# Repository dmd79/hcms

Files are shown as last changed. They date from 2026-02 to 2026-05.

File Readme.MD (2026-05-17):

# HCMS Scientific Calculator

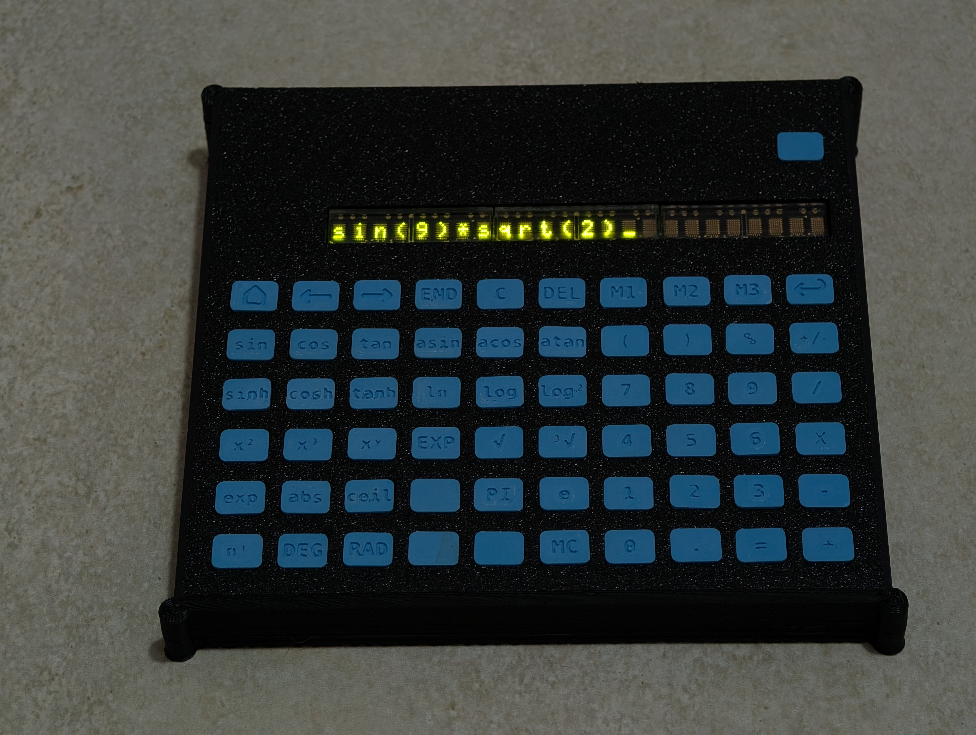
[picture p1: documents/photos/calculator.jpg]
HCMS Scientific Calculator


A handmade scientific calculator built with an ESP32-S3 microcontroller, Broadcom HCMS-2913 LED dot-matrix displays, and a custom 6×10 matrix keypad — all running on [ESPHome](https://esphome.io/).

---

## Features

- 24-character scrolling LED display (3× HCMS-2913 chained)
- 60-key matrix keypad (6 rows × 10 columns)
- Full scientific calculator: arithmetic, trigonometry, logarithms, powers, factorials, constants
- Degree / Radian toggle
- 3-slot memory system (MEM1, MEM2, MEM3 + MCLR)
- UNDO function
- Cursor navigation (HOME, END, `<`, `>`, DEL)
- Settings menu: brightness, display timeout, auto power-off, firmware version
- Auto power-off with configurable timeout
- Autorepeat on `<`, `>`, DEL
- LiPo battery powered with USB-C charging

---

## Supported Operations

| Category | Keys |
|---|---|
| Arithmetic | `+` `-` `×` `/` `%` `=` `+/-` |
| Powers | `x²` `x³` `xʸ` `√x` |
| Trigonometry | `sin` `cos` `tan` `asin` `acos` `atan` `sinh` `cosh` `tanh` |
| Logarithms | `log` `ln` `log2` `exp` `eˣ` |
| Rounding | `floor` `ceil` `round` `abs` |
| Constants | `e` `π` |
| Angle mode | `deg` `rad` |
| Memory | `MEM1` `MEM2` `MEM3` `MCLR` |
| Editing | `DEL` `UNDO` `HOME` `END` `<` `>` `CANC` |

---

## Hardware

### Main Components

| Component | Description |
|---|---|
| ESP32-S3-WROOM-1-N16R8 | Main microcontroller (16MB flash, 8MB PSRAM) |
| HCMS-2913 × 3 | 5×7 dot-matrix LED display modules, chained |
| KH-6×6×6H tactile switches × 60 | Matrix keypad switches |

### Power Supply

The calculator is powered by a single-cell LiPo battery. Two additional modules are required:

**LiPo Charger (USB-C)** — charges the battery via USB-C connector.  
[Buy on Amazon (R3028, 18×14mm)](https://www.amazon.it/dp/B0F59VQ8JC)

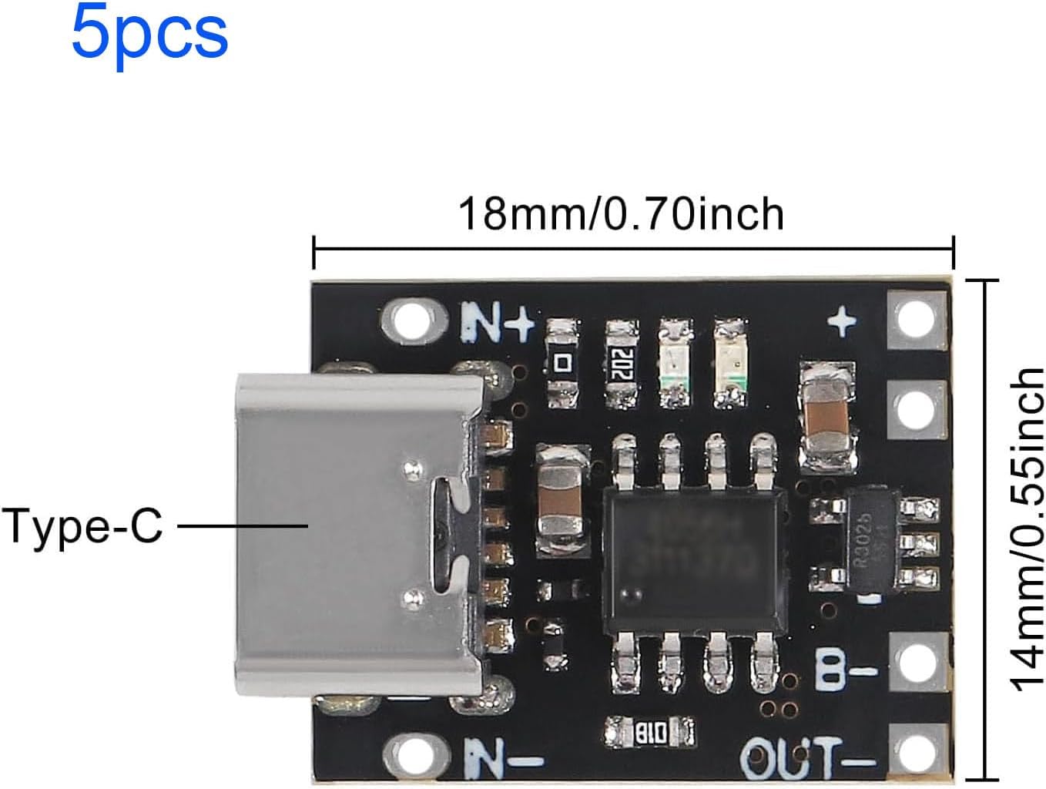
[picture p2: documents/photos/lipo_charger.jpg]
LiPo Charger


**DC-DC Step-Down Converter** — converts battery voltage to a stable 3.3V for the ESP32 and display logic.  
[Buy on Amazon (Mini DC-DC, adjustable)](https://www.amazon.it/Converter-LAOMAO-convertitore-regolabile-alimentatore/dp/B0B932CTQJ/)

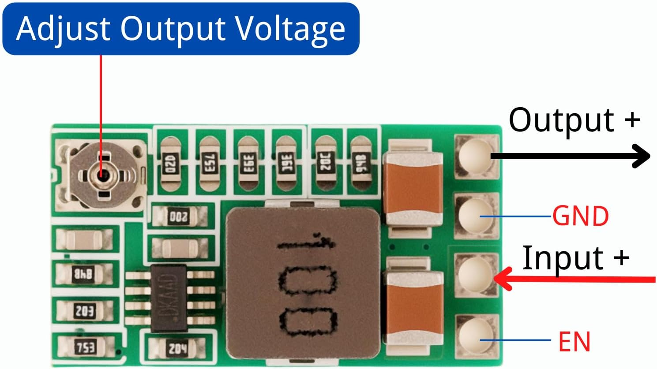
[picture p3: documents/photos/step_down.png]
Step-Down Converter


> ⚠️ **Important — Step-Down Configuration:**  
> This module ships with an adjustable trimmer. To fix the output at exactly 3.3V:
> 1. **Desolder the trimmer** on the front of the board.
> 2. **Bridge the 3.3V pad** on the back of the board with a blob of solder.
>
> The back of the board has clearly labeled voltage pads: `1.8V`, `2.5V`, `3V`, `3.3V`, `5V`, `9V`, `12V`, `ADJ`. Bridge only the `3.3V` pad.

---

## PCB

The custom PCB was designed in EasyEDA. It hosts the ESP32-S3 module, the three HCMS-2913 displays, the 6×10 key matrix, reset and boot buttons, programming header, and the battery/power connectors.

- [📄 Schematic (PDF)](documents/schematics/schematic.pdf)
- [📦 Gerber files (ZIP)](documents/gerber/Gerber_PCB1_2026-05-17.zip)

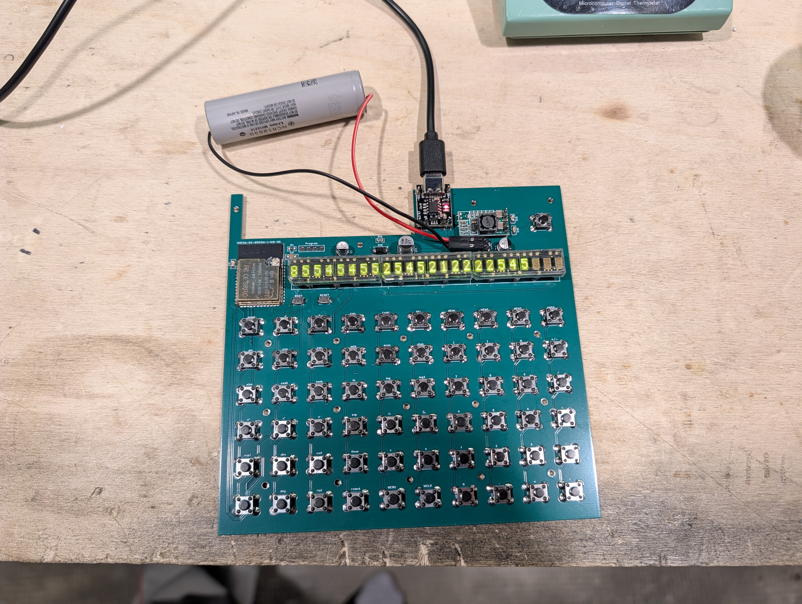
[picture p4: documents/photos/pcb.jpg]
PCB


---

## 3D Printed Parts

The enclosure and keycaps are 3D printed. The keycaps feature recessed cavities designed to be filled with acrylic paint for labeling.

| File | Description |
|---|---|
| [top.stl](documents/stl/top.stl) | Top shell of the enclosure |
| [bottom.stl](documents/stl/bottom.stl) | Bottom shell of the enclosure |
| [key.stl](documents/stl/key.stl) | Keycap (print 60×) |

**Printing notes:**
- Material: PLA
- Keycap finish: increase top solid layers (5+) for a smoother surface before painting
- Paint fill: acrylic paint in the recessed cavity, wipe excess when wet

---

## Firmware

The firmware is built with [ESPHome](https://esphome.io/). It implements:

- HCMS-2913 SPI-based display driver (custom C++ component)
- 6×10 matrix keypad scanner
- Shunting-Yard algorithm parser (`Calculator.cpp`)
- Display scrolling, cursor blinking, settings menu
- Auto power-off via `last_key_time` global + 1s interval

---

## License

This project is open source. Feel free to use, modify, and share it.

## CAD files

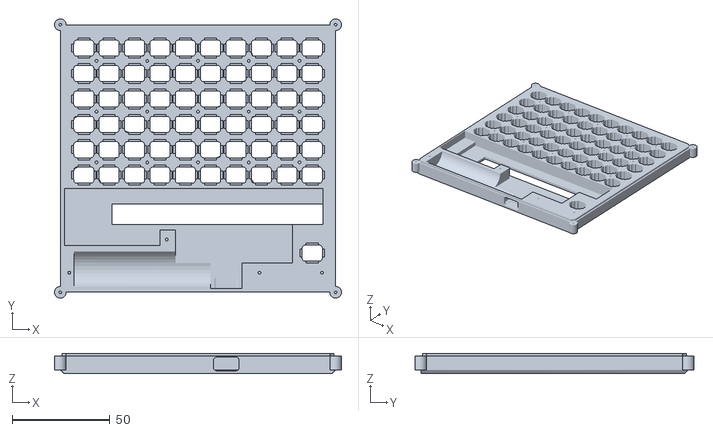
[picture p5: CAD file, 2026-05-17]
documents/stl/top.stl
147.0 x 143.0 x 10.5

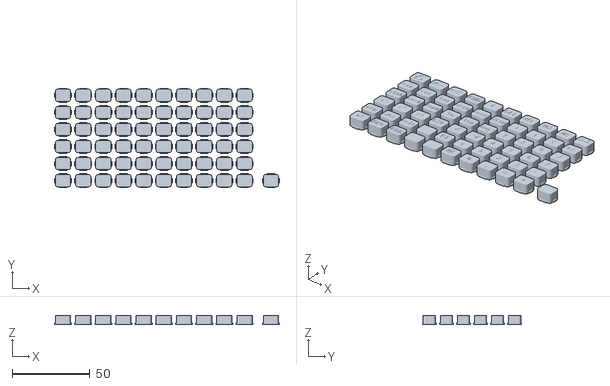
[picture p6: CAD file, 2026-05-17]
documents/stl/key.stl
145.0 x 64.0 x 6.00

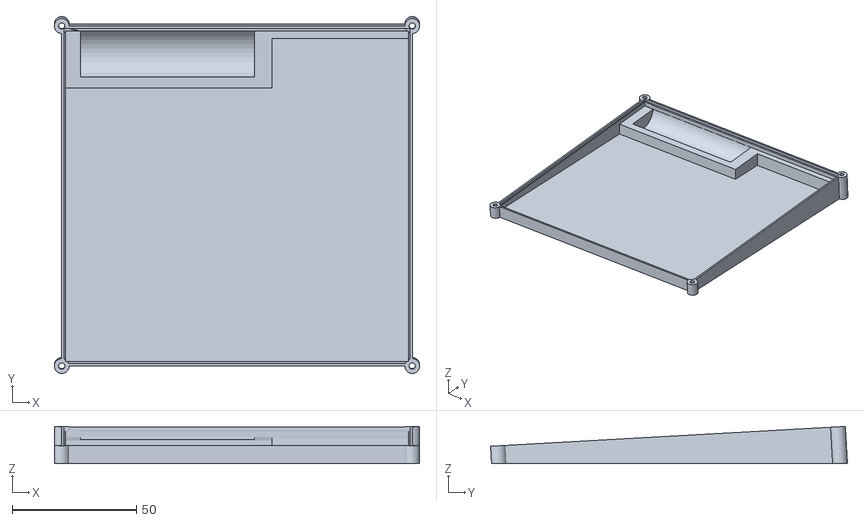
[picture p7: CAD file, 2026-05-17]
documents/stl/bottom.stl
147.0 x 143.6 x 15.0

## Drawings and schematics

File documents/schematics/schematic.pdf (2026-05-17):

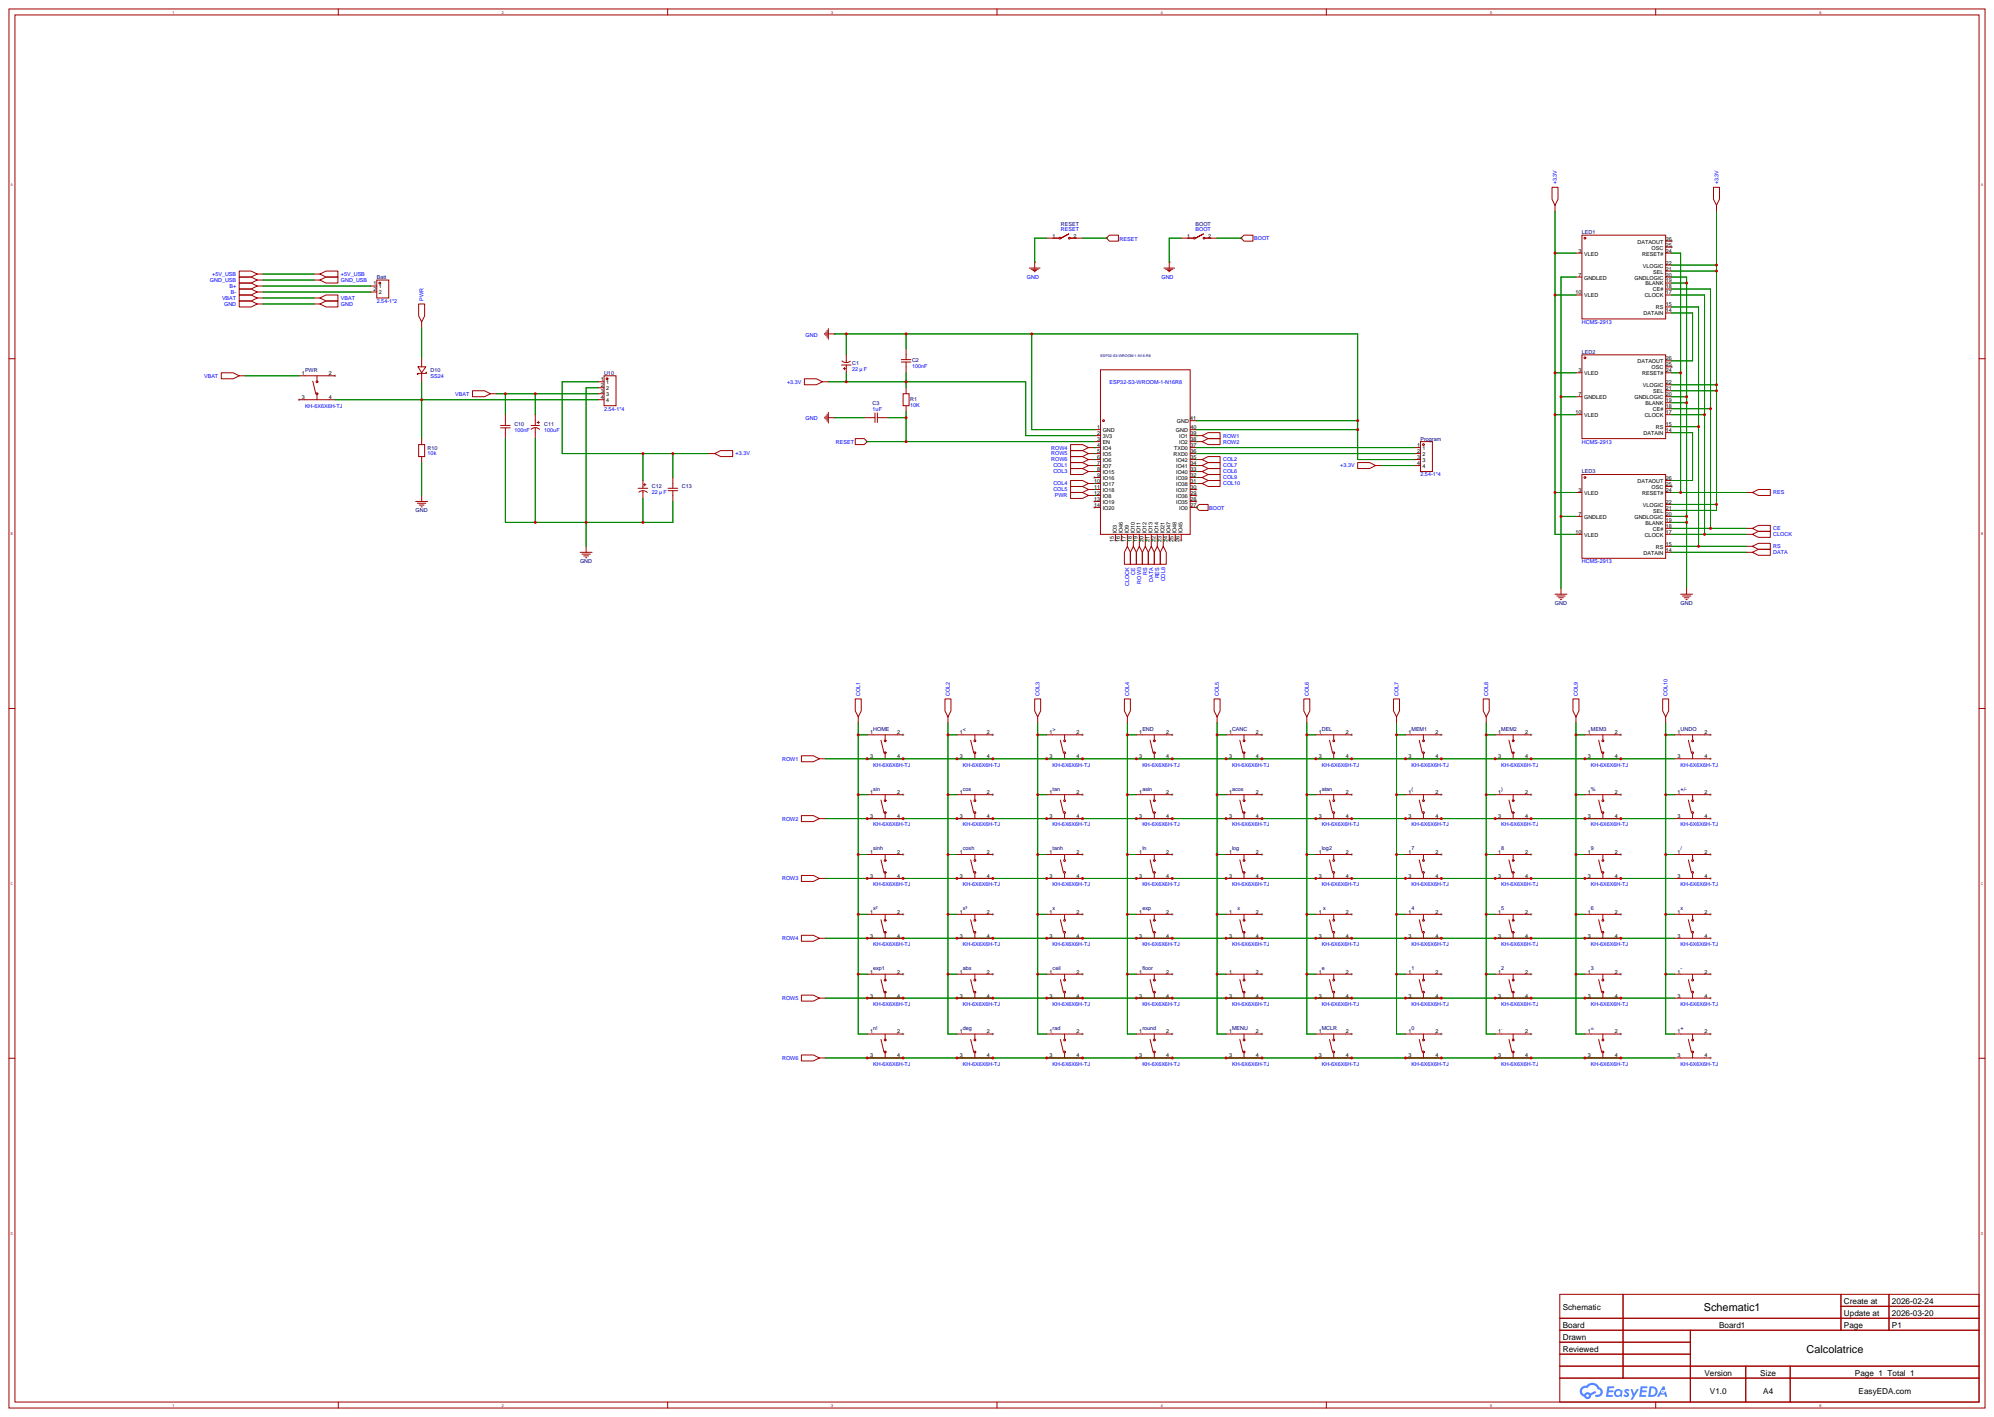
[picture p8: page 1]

Schematic | Schematic1 | Create at | 2026-02-24

Update at | 2026-03-20

Board | Board1 | Page | P1
Drawn | | Calcolatrice
Reviewed

Version | Size | Page 1 Total 1
V1.0 | A4 | EasyEDA.com

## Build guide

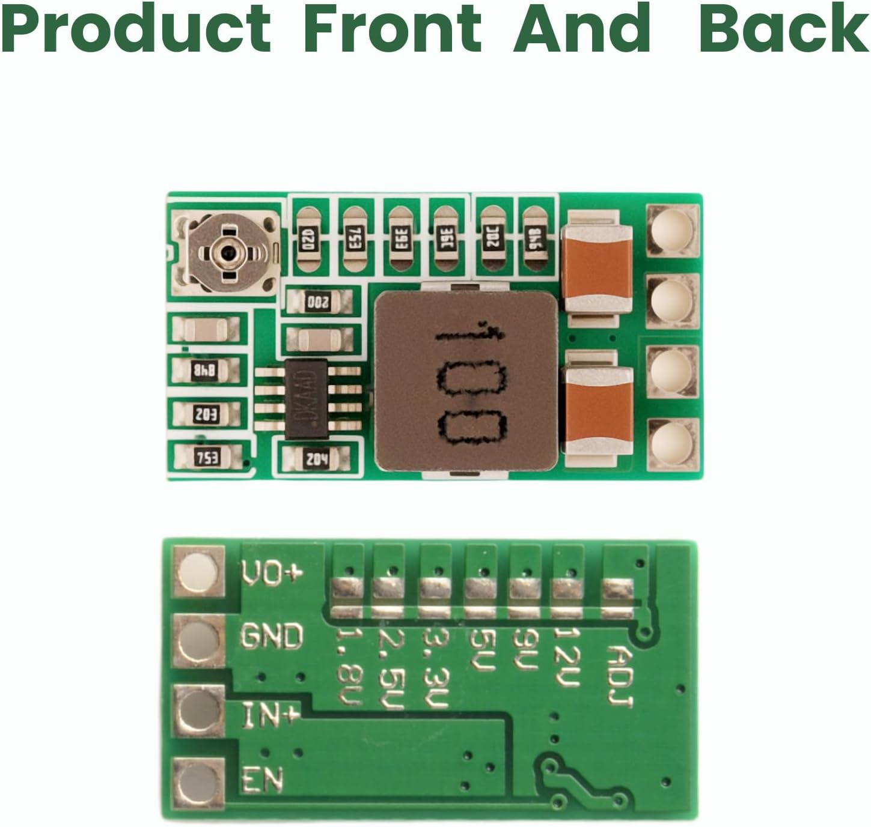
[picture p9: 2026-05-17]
documents/photos/step_down_2.png

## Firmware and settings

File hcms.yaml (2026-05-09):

esphome:
  name: hcms
  friendly_name: hcms
  platformio_options:
    board_build.flash_mode: dio
    build_unflags: -Werror=all
  includes:
    - LedDisplay/LedDisplay.cpp
    - LedDisplay/LedDisplay.h
    - LedDisplay/Font5x7.h
    - Calculator/Calculator.cpp
    - Calculator/Calculator.h
  on_boot:
    then:
      - lambda: |-
          static auto my_display_1 = new LedDisplay(13, 12, 9, 10, 14, 24);
          my_display_1->begin();
          my_display_1->clear();
          my_display_1->setBrightness((int)id(display_brightness).state);

          // Imposta cursore alla fine del buffer all'avvio
          id(cursor_pos) = id(buffer).length();
          id(last_key_time) = millis();
          return;

preferences:
  flash_write_interval: 0s

packages:
  keyboard: !include Calculator/keyboard.yaml

esp32:
  board: esp32-s3-devkitc-1
  variant: esp32s3
  flash_size: 16MB
  cpu_frequency: 240MHz
  framework:
    type: esp-idf
    sdkconfig_options:
      COMPILER_OPTIMIZATION_SIZE: y
      CONFIG_ESP32S3_DEFAULT_CPU_FREQ_240: "y"
      CONFIG_ESP32S3_DATA_CACHE_64KB: "y"
      CONFIG_ESP32S3_DATA_CACHE_LINE_64B: "y"

light:
  - platform: esp32_rmt_led_strip
    id: display_moodlight
    rgb_order: RGB
    pin: GPIO48
    num_leds: 1
    chipset: ws2812
    use_psram: true
    name: "My Light"

logger:

api:
  encryption:
    key: !secret api_hcms

ota:
  platform: esphome
  password: !secret ota_hcms

wifi:
  networks:
  - ssid: !secret wifi_ssid
    password: !secret wifi_password
  - ssid: !secret wifi_ssid_ha
    password: !secret wifi_password
  manual_ip:
    static_ip: 192.168.188.83
    gateway: 192.168.188.1
    subnet: 255.255.255.0
  ap:
    ssid: "Hcms Fallback Hotspot"
    password: "k6O8BTRS0byE"

web_server:
  port: 80
  version: 2

external_components:
  - source:
      type: local
      path: LedDisplay

switch:
  - platform: gpio
    pin: 8
    id: power_enable
    restore_mode: ALWAYS_ON

# =====================
# VARIABILI GLOBALI
# =====================
globals:
  - id: a
    type: double
    initial_value: '0'
  - id: b
    type: double
    initial_value: '0'
  - id: result
    type: double
    initial_value: '0'
  - id: op
    type: char
    initial_value: "' '"
  - id: last_was_result
    type: bool
    initial_value: 'false'
  - id: pending_op
    type: char
    initial_value: ' '
  - id: calc_buffer
    type: std::string
    restore_value: false
    initial_value: ""
  - id: buffer
    type: std::string
    restore_value: false
    initial_value: ""
  - id: cursor_pos
    type: int
    initial_value: '0'
  - id: paren_alert
    type: bool
    initial_value: 'false'
  - id: paren_alert_count
    type: int
    initial_value: '0'
  - id: last_formula
    type: std::string
    restore_value: false
    initial_value: ""

  - id: settings_mode
    type: bool
    initial_value: 'false'

  - id: settings_press_count
    type: int
    initial_value: '0'

  - id: display_timeout_min
    type: int
    restore_value: true
    initial_value: '1'
  - id: mem1
    type: std::string
    restore_value: true
    initial_value: ""
  - id: mem2
    type: std::string
    restore_value: true
    initial_value: ""
  - id: mem3
    type: std::string
    restore_value: true
    initial_value: ""
  - id: last_key_time
    type: uint32_t
    initial_value: '0'

  - id: repeat_left_active
    type: bool
    initial_value: 'false'
  - id: repeat_left_start
    type: uint32_t
    initial_value: '0'

  - id: repeat_right_active
    type: bool
    initial_value: 'false'
  - id: repeat_right_start
    type: uint32_t
    initial_value: '0'

  - id: repeat_del_active
    type: bool
    initial_value: 'false'
  - id: repeat_del_start
    type: uint32_t
    initial_value: '0'

  - id: repeat_last_fire
    type: uint32_t
    initial_value: '0'
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

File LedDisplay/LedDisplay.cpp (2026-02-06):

/*
  LedDisplay -- controller library for Avago HCMS-297x displays
  Modified for ESP-IDF with ESPHome support
  
  Copyright (c) 2009 Tom Igoe. Some right reserved.
  Revisions by Mark Liebman, 27 Jan 2010
*/

#include "LedDisplay.h"
#include "Font5x7.h"

// Helper functions for ESP-IDF (not needed for ESPHome)
#ifndef ESPHOME

static void pinMode(uint8_t pin, uint8_t mode) {
    gpio_config_t io_conf = {};
    io_conf.intr_type = GPIO_INTR_DISABLE;
    io_conf.mode = (gpio_mode_t)mode;
    io_conf.pin_bit_mask = (1ULL << pin);
    io_conf.pull_down_en = GPIO_PULLDOWN_DISABLE;
    io_conf.pull_up_en = GPIO_PULLUP_DISABLE;
    gpio_config(&io_conf);
}

static void digitalWrite(uint8_t pin, uint8_t val) {
    gpio_set_level((gpio_num_t)pin, val);
}

static void delay(uint32_t ms) {
    vTaskDelay(ms / portTICK_PERIOD_MS);
}

static void shiftOut(uint8_t dataPin, uint8_t clockPin, uint8_t bitOrder, uint8_t val) {
    for (uint8_t i = 0; i < 8; i++) {
        if (bitOrder == LSBFIRST) {
            digitalWrite(dataPin, !!(val & (1 << i)));
        } else {
            digitalWrite(dataPin, !!(val & (1 << (7 - i))));
        }
        digitalWrite(clockPin, HIGH);
        digitalWrite(clockPin, LOW);
    }
}

#else
// ESPHome - use ESPHome's GPIO functions
static void shiftOut(uint8_t dataPin, uint8_t clockPin, uint8_t bitOrder, uint8_t val) {
    auto data_gpio = new GPIOPin();
    data_gpio->set_pin(dataPin);
    data_gpio->setup();
    
    auto clock_gpio = new GPIOPin();
    clock_gpio->set_pin(clockPin);
    clock_gpio->setup();
    
    for (uint8_t i = 0; i < 8; i++) {
        if (bitOrder == LSBFIRST) {
            data_gpio->digital_write(!!(val & (1 << i)));
        } else {
            data_gpio->digital_write(!!(val & (1 << (7 - i))));
        }
        clock_gpio->digital_write(true);
        clock_gpio->digital_write(false);
    }
    
    delete data_gpio;
    delete clock_gpio;
}

static void pinMode(uint8_t pin, uint8_t mode) {
    auto gpio = new GPIOPin();
    gpio->set_pin(pin);
    gpio->setup();
    gpio->pin_mode(mode == OUTPUT ? gpio::FLAG_OUTPUT : gpio::FLAG_INPUT);
    delete gpio;
}

static void digitalWrite(uint8_t pin, uint8_t val) {
    auto gpio = new GPIOPin();
    gpio->set_pin(pin);
    gpio->setup();
    gpio->digital_write(val);
    delete gpio;
}

static void delay(uint32_t ms) {
    delayMicroseconds(ms * 1000);
}
#endif

// Constructor
LedDisplay::LedDisplay(uint8_t _dataPin,
                       uint8_t _registerSelect,
                       uint8_t _clockPin,
                       uint8_t _chipEnable,
                       uint8_t _resetPin,
                       uint8_t _displayLength)
{
    this->dataPin = _dataPin;
    this->registerSelect = _registerSelect;
    this->clockPin = _clockPin;
    this->chipEnable = _chipEnable;
    this->resetPin = _resetPin;
    this->displayLength = _displayLength;
    this->cursorPos = 0;

    if (_displayLength > LEDDISPLAY_MAXCHARS) {
        this->displayLength = LEDDISPLAY_MAXCHARS;
    }

    for (unsigned int i = 0; i < sizeof(stringBuffer); i++) {
        stringBuffer[i] = ' ';
    }
    stringBuffer[sizeof(stringBuffer) - 1] = '\0';
    
    this->setString(stringBuffer);
}

void LedDisplay::begin() {
    pinMode(dataPin, OUTPUT);
    pinMode(registerSelect, OUTPUT);
    pinMode(clockPin, OUTPUT);
    pinMode(chipEnable, OUTPUT);
    pinMode(resetPin, OUTPUT);

    digitalWrite(resetPin, LOW);
    delay(10);
    digitalWrite(resetPin, HIGH);

    loadDotRegister();
    loadAllControlRegisters(0b01111111);
}

void LedDisplay::clear() {
    this->setString(stringBuffer);
    for (int displayPos = 0; displayPos < displayLength; displayPos++) {
        writeCharacter(' ', displayPos);
    }
    loadDotRegister();
}

void LedDisplay::home() {
    this->cursorPos = 0;
}

void LedDisplay::setCursor(int whichPosition) {
    this->cursorPos = whichPosition;
}

int LedDisplay::getCursor() {
    return this->cursorPos;
}

size_t LedDisplay::write(uint8_t b) {
    if (cursorPos >= 0 && cursorPos < displayLength) {
        writeCharacter(b, cursorPos);
        if (this->displayString == stringBuffer && cursorPos < LEDDISPLAY_MAXCHARS) {
            stringBuffer[cursorPos] = b;
        }
        cursorPos++;
        loadDotRegister();
    }
    return 1;
}

void LedDisplay::scroll(int direction) {
    cursorPos += direction;
    int stringEnd = strlen(displayString);

    for (int displayPos = 0; displayPos < displayLength; displayPos++) {
        int whichCharacter = displayPos - cursorPos;
        char charToShow;
        if ((whichCharacter >= 0) && (whichCharacter < stringEnd)) {
            charToShow = displayString[whichCharacter];
        } else {
            charToShow = ' ';
        }
        writeCharacter(charToShow, displayPos);
    }
    loadDotRegister();
}

void LedDisplay::setString(const char *_displayString) {
    this->displayString = _displayString;
}

const char *LedDisplay::getString() {
    return displayString;
}

int LedDisplay::stringLength() {
    return strlen(displayString);
}

void LedDisplay::setBrightness(uint8_t bright) {
    if (bright > 15) {
        bright = 15;
    }
    loadAllControlRegisters(0b01110000 + bright);
}

void LedDisplay::writeCharacter(char whatCharacter, uint8_t whatPosition) {
    uint8_t thisPosition = whatPosition * 5;

    for (int i = 0; i < 5; i++) {
        dotRegister[thisPosition + i] = Font5x7[((whatCharacter - 0x20) * 5) + i];
    }
}

void LedDisplay::loadControlRegister(uint8_t dataByte) {
    digitalWrite(registerSelect, HIGH);
    digitalWrite(chipEnable, LOW);
    shiftOut(dataPin, clockPin, MSBFIRST, dataByte);
    digitalWrite(chipEnable, HIGH);
}

void LedDisplay::loadAllControlRegisters(uint8_t dataByte) {
    int chip_count = displayLength / 4;

    for (int i = 0; i < chip_count; i++) {
        loadControlRegister(0b10000001);
    }

    loadControlRegister(dataByte);
    loadControlRegister(0b10000000);
}

void LedDisplay::loadDotRegister() {
    int maxData = displayLength * 5;

    digitalWrite(registerSelect, LOW);
    digitalWrite(chipEnable, LOW);
    for (int i = 0; i < maxData; i++) {
        shiftOut(dataPin, clockPin, MSBFIRST, dotRegister[i]);
    }
    digitalWrite(chipEnable, HIGH);
}

int LedDisplay::version(void) {
    return 4;
}

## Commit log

2026-02-07 hcms: UNDO button
2026-02-08 hcms: MEM buttons
2026-02-08 hcms: MEM clear button
2026-03-14 hcms: add matrix keyboard and move to ESP32-S3
2026-03-14 hcms: automatic power off
2026-05-09 hcms: add settings key
    Brightness from 1 to 15
    Timeout from 1 to 60 minutes
    Power off
    FW version
2026-05-09 hcms: fix use %.15g for result formatting, reset buffer on DEL after result
    [hcms.yaml]
2026-05-17 hcms: add Readme
    [bottom.stl, key.stl, top.stl]
